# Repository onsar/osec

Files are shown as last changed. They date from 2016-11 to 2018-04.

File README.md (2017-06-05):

# osec
###Proyecto de para el desarrollo de un demostrador de software libre para el control de la energía

En la primera fase monitorizamos una instalación solar fotovoltaica mixta que esta compuesta por paneles fotovoltaicos y térmicos. Los tipos de sensores que incluye son:

* Intensidad en continua
* Temperatura del agua
* Caudal
* Presión del circuito hidráulico

En una segunda fases optimizaremos el circuito

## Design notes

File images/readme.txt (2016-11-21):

En este directorio actualizaremos las imágenes que vayamos a usar en la documentación del proyecto

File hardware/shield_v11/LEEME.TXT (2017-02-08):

Esta versión incorpora la alimentación directa de la entrada al RD-xx15

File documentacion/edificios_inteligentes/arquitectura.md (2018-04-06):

# Descripción de la arquitectura

El sistema de control inteligente MeshControl está formado por una serie de componentes que abarca desde los sensores y actuadores anteriormente nombrados, al software y hardware de la unidad interior. La tecnología de la que se compone MeshControl es abierta, permitiendo y facilitando su acceso a fabricantes e instaladores que quieran implementarla en sus sistemas. Por ello, la licencia bajo la que se distribuirá el producto es GPL (General Public License), lo que garantiza la colaboración entre los usuarios y redunda en una mejora continua del sistema. 

## Hardware

Siguiendo los principios de la tecnología abierta, el hardware del proyecto se ha desarrollado bajo licencias libres de manera que esta solución se pueda replicar en otras aplicaciones o modificar para adaptarlo a las necesidades específicas de una instalación. Por ello, el hadware específico desarrollado para este proyecto está basado en los microcontroladores de Atmel, que son el corazón de Arduino. Para los módulos que necesiten prestaciones más altas se usa la Raspberry Pi y el hardware Olimex. 
El dispositivo físico que se dispondrá en cada instalación solar está basado en una PCB (Printed Circuit Board), a la cual se ha integrado uno de estos microcontroladores que se encarga del control de la información. Junto al microcontrolaador se incluye también el integrado ESP 8266, fabricado por Espressif, un módulo WIFI de fácil manejo y muy económico, capaz de conectar cualquier dispositivo a la red y cuyo uso se está extendiendo notablemente en las soluciones de IoT. Este chip es por tanto el encargado de transmitir la información recibida a la nube.

## Software

La información obtenida a través de los distintos canales de entrada se almacena en una base de datos localizada en la nube, concretamente en un servidor habilitado para cada instalación. La transmisión de información desde la fuente local al servidor se realiza mediante protocolos Restful y Mqtt, este último muy usado en soluciones IoT debido al poco consumo de recursos que conlleva. A diferencia de otros sistemas de control, diseñados para sistemas solares, el software específico de MeshControl se aloja directamente en el servidor, de manera que la información recibida es procesada directamente ahí. Este hecho constituye una ventaja fundamental, ya que facilita su acceso desde cualquier punto con conexión a internet a la vez que se favorece la integración con otros servicios que alojados en la nube. El servidor desarrollado está basado en PHP y JavaScript que permiten tanto al técnico responsable como al usuario final acceder directamente a sus datos registrados, visualizar estadísticas y consumos o modificar parámetros de funcionamiento del sistema. Para ello, se ha tomado como referencia el software Emoncms, el cual se ha modificado para cubrir las exigencias de los sistemas solares híbridos.
La comunicación entre el servidor y actuadores se ejecuta también mediante protocolos Restful y Mqtt. Se ha hecho especial hincapié en el uso de protocolos web y redes WIFI con el fin de aumentar la flexibilidad del sistema de control, ya que de esta manera se reducen las infraestructuras de cableado y sus problemas típicos asociados. Además, actualmente los dispositivos WIFI son una tecnología robusta, extendida y de precio muy competitivo, que junto con el envío de información mediante protocolo Mqtt redunda en un consumo de energía muy reducido.

[MODIFICAR IMAGEN]

La implementación del servidor en la nube respalda directamente la premisa del Internet de las Cosas, ya que la información se recibe, se muestra y se gestiona desde internet. Este tratamiento presenta varias ventajas clave sobre otros sistemas de control efectuados en tecnologías solares. En primer lugar transporta el sistema de control fuera de la instalación física, lo que evita el traslado del técnico especialista hasta el entorno real cada vez que haya que ejecutar una modificación o reparar una avería. Por contra, ese control se lleva a un entorno en la nube que es fácilmente accesible por todos los agentes (técnico, instalador, usuario final) y al que se puede llegar con una simple conexión a internet. Al crear un servidor para cada instalación se reduce el riesgo de provocar problemas que afecten a un gran número de usuarios, mientras que se favorece por otra parte, la adecuación del software a las necesidades de cada instalación en particular. Por último, generar un entorno en la nube donde el usuario final pueda revisar periódicamente la producción y consumos de su vivienda, ayuda a visualizar y a tomar conciencia de su propia gestión energética y de los beneficios obtenidos mediante el control inteligente de la instalación solar, lo que puede contribuir a aumentar la confianza en dicha tecnología.

## La robustez del sistema
Los microcontroladores, que recopilan la información de la red de sensores y ejecutan las acciones, leen del sistema en la nube cual debe ser su comportamiento (actualizan su software) lo que protege a MEshControl contra fallos en las comunicaciones o en el propio servidor. Esta característica proporciona un sistema robusto que funcionará ante cualquier contingencia y que a la vez se beneficia de todas las ventajas de estar en la nube.

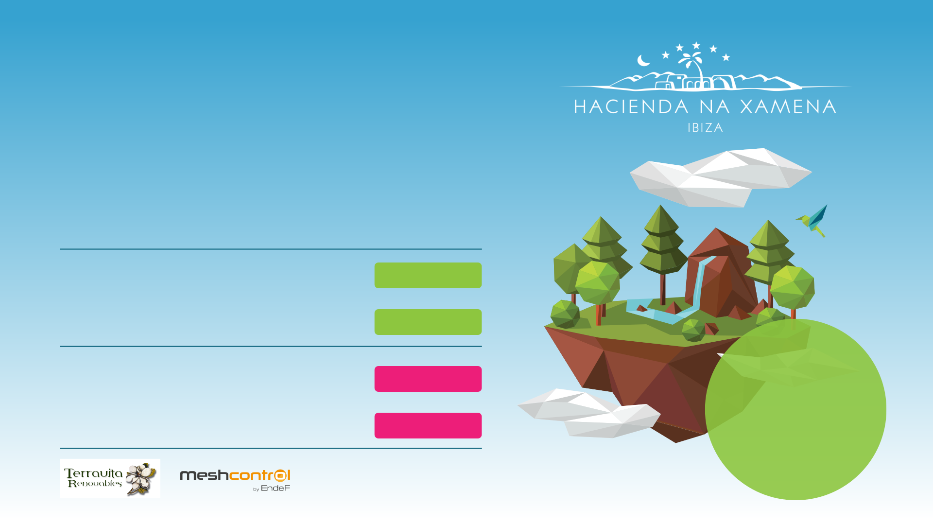
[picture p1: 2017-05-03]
interfaz.a-desarrollo/img/back.png

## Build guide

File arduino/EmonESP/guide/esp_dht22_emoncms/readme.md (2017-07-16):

# ESP DHT22 to Emoncms Example

An example made using the [Adafruit Huzzah](https://www.adafruit.com/product/2471) board with ESP-12 module and the DHT22 temperature humidity sensor.

This code example, when loaded onto the ESP will continuously upload temperature and humidity data onto [emoncms.org](https://emoncms.org)

[CP2102 USB to UART adapter](https://shop.openenergymonitor.com/programmers) was used as power supply and to program the ESP. 
PlatformIO or Arduino IDE can be used to compile and upload code. See [PlatformIO compile and upload guide](https://guide.openenergymonitor.org/technical/compiling)

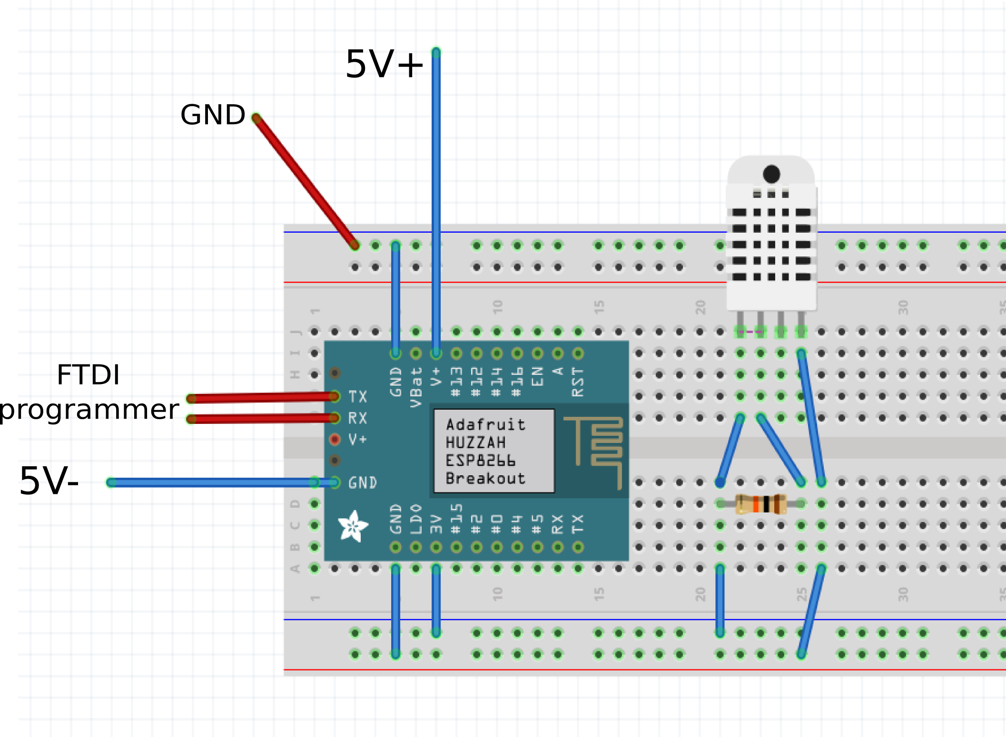
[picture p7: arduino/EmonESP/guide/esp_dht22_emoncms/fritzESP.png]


Thanks to @myrddinmuse for puting together this example.

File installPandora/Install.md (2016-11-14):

Insatalacion de pandora en un sistema debian, incluyendo consola, servidor y agente.

Para empezar descargamos los paquetes desde el siguiente enlace: Enlace (https://pandorafms.org/en/features/free-download-monitoring-software/)

Luego instalamos los paquetes con los siguientes comandos <br>
  <code>### XXX es la version del paquete.  </code><br>
  <code># dpkg -i pandorafms.console_XXX.deb  </code><br>
  <code># apt-get -f install  </code><br>
  <code># dpkg -i pandorafms.server_XXX.deb </code><br>
  <code># apt-get -f install </code><br>
  <code># dpkg -i pandorafms.agent_XXX.deb  </code><br>
  <code># apt-get -f install  </code><br>

Ahora hay que instalar el servidor de la base de datos MySQL <br><br>
  <code># apt-get install mysql-server </code><br><br>
En esta instalacion pedira un usuario y contraseña para el usuario administrador de la base de datos.

Despues se modifica el fichero “etc/apache2/sites-enabled/000-default.conf” para hacer de la consola la pagina de inicio
cambiando la linea “DocumentRoot /var/www/pandora_console”. Y se reinicia el servicio de apache con el siguiente comando:
  <br><br>
  <code># /etc/init.d/apache2 restart </code><br><br>

Luego de reiniciar el servicio abrimos un navegador y vamos a la ip del servidor (o a localhost si estamos en el servidor)
  <br><br>
  <code>http://192.168.xxx.xxx/install.php</code><br>
  o<br>
  <code>http://localhost/install.php</code><br><br>
  
En esta instalacion debemos darle usuario y clave de la base de datos MySQL a la consola de pandora. <br>
Es importante escribir la contraseña que nos da pandora durante la instalacion, en:
  <br><br>
  <code># /etc/pandora/pandora_server.conf</code><br>
  <code>systemctl restart pandora_server.service</code>

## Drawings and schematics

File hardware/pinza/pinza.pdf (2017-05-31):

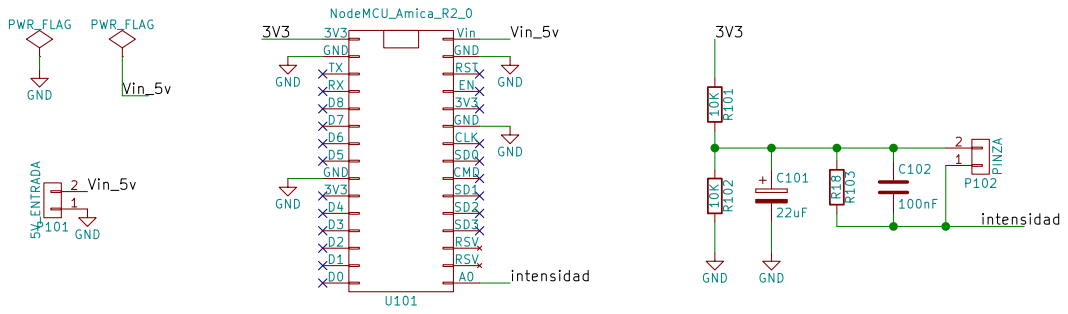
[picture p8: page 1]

File: pinza.sch Sheet: /
Id: 1/1 Title:

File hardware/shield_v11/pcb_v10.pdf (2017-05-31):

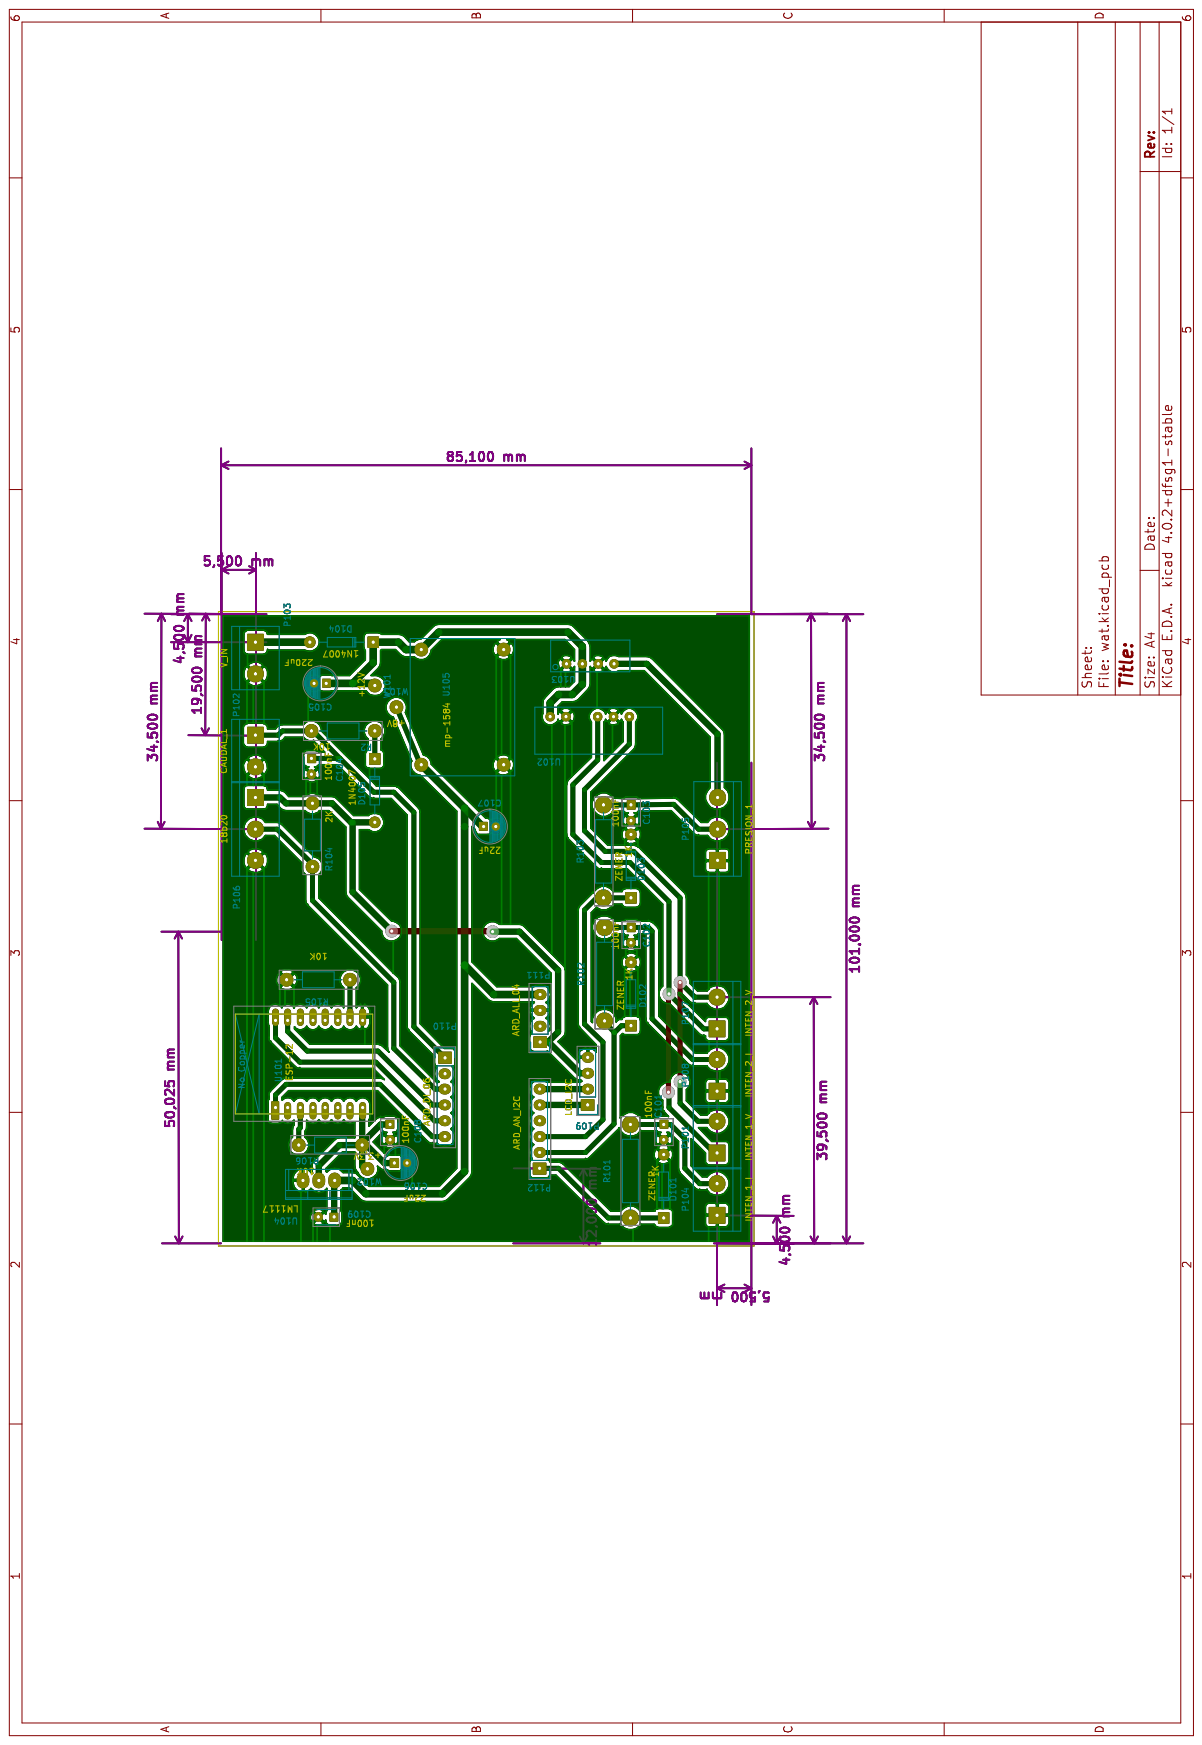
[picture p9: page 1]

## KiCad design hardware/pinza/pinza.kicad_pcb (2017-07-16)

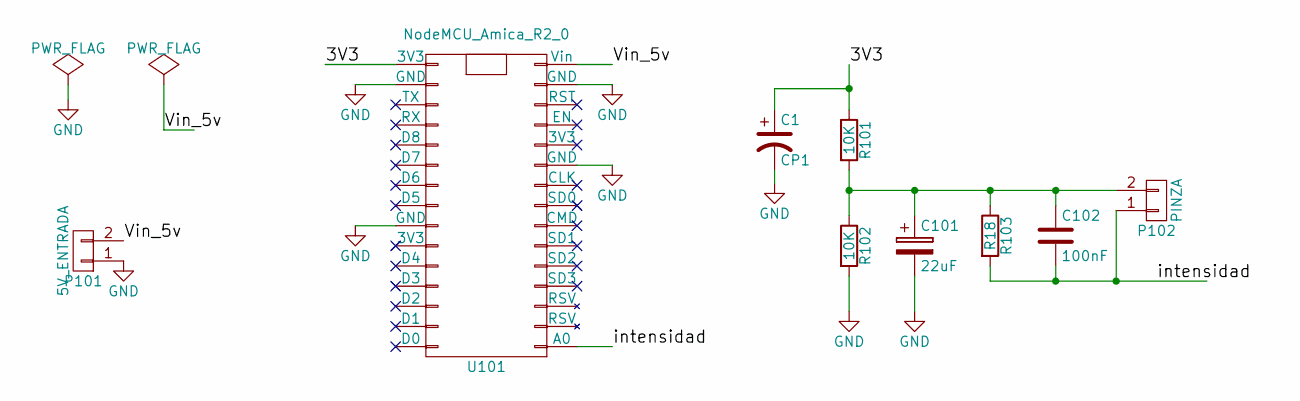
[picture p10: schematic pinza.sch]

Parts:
C1: CP1; C_Radial_D5_L11_P2
C101: 22uF; C_Radial_D5_L11_P2
C102: 100nF; C_Disc_D3_P2.5
P101: 5V_ENTRADA; bornier2
P102: PINZA; bornier2
R101, R102: 10K; Resistor_Horizontal_RM10mm
R103: R18; Resistor_Horizontal_RM10mm
U101: NodeMCU_Amica_R2_0; NodeMCU_Amica_R2

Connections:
/3V3: C1.1, R101.1, U101.16 (3V3)
/Vin_5v: P101.2, U101.15 (Vin)
/intensidad: C102.2, P102.1, R103.2, U101.1 (A0)
GND: C1.2, C101.2, P101.1, R102.2, U101.10 (GND), U101.14 (GND), U101.17 (GND), U101.24 (GND)
unnamed: C101.1, C102.1, P102.2, R101.2, R102.1, R103.1

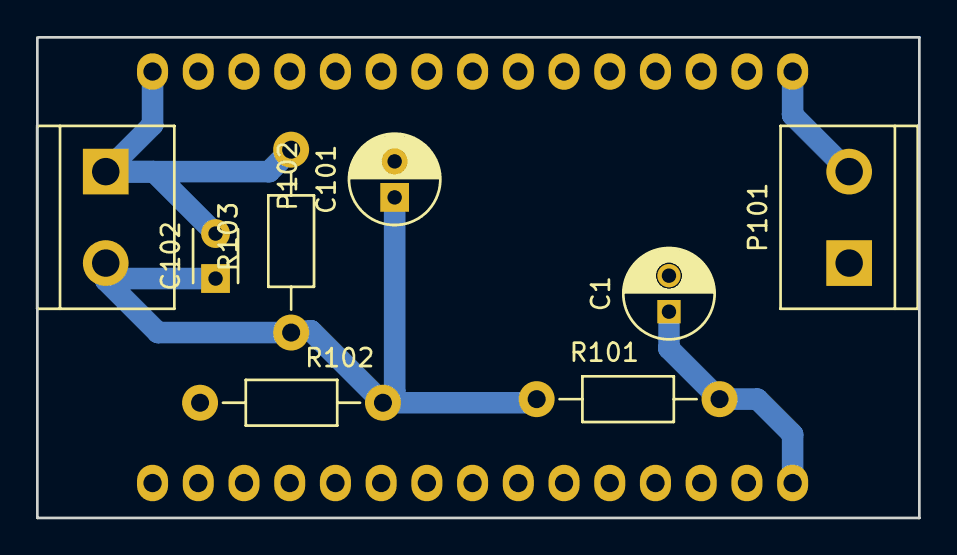
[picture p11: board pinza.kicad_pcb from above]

Board: 2 copper layers, 49.0 x 26.7 mm, 9 parts (1 on the bottom side), 5 nets.

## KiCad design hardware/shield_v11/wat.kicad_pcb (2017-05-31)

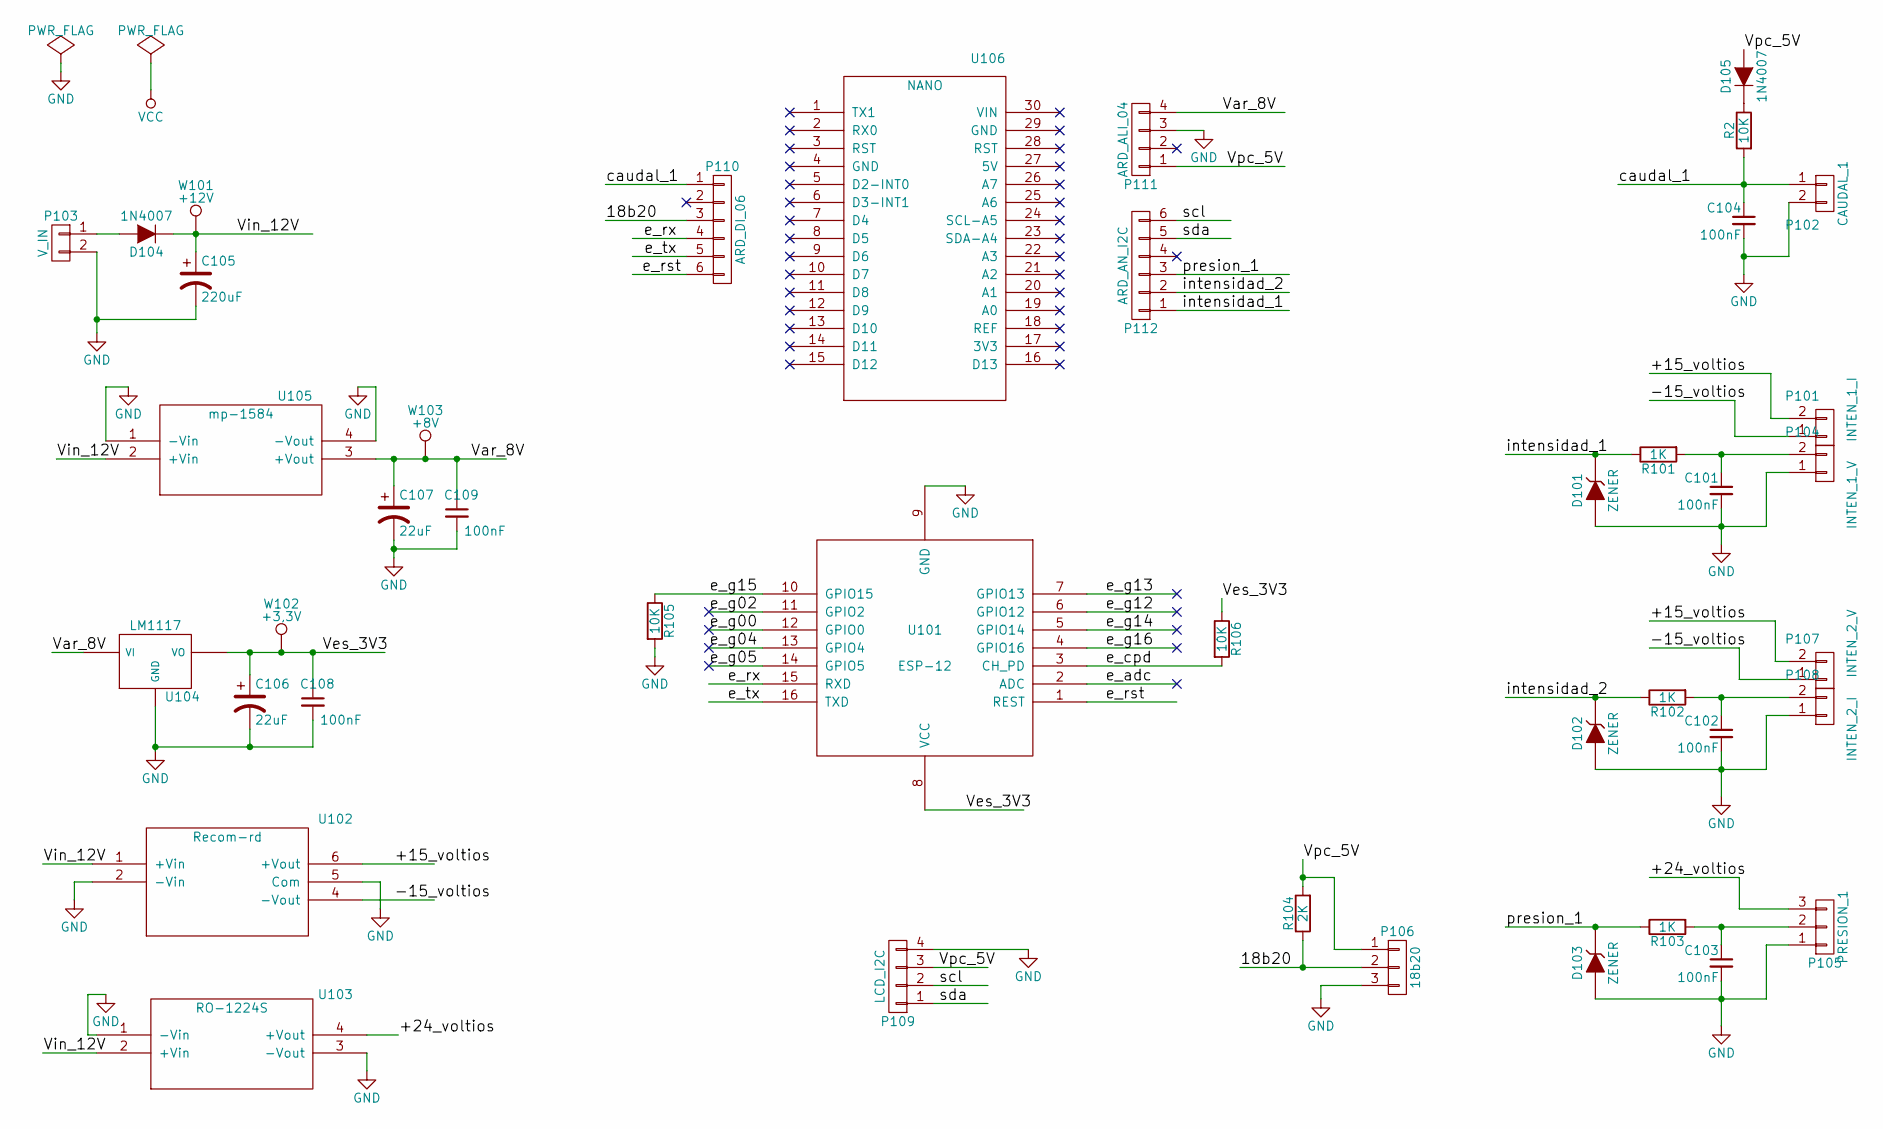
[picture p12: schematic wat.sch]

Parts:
C101, C102, C103, C104, C108, C109: 100nF; C_Disc_D3_P2.5
C105: 220uF; C_Radial_D5_L11_P2
C106, C107: 22uF; C_Radial_D5_L11_P2
D101, D102, D103: ZENER; Diode_DO-35_SOD27_Horizontal_RM10
D104, D105: 1N4007; Diode_DO-35_SOD27_Horizontal_RM10
P101: INTEN_1_V; bornier2
P102: CAUDAL_1; bornier2
P103: V_IN; bornier2
P104: INTEN_1_I; bornier2
P105: PRESION_1; bornier3
P106: 18b20; bornier3
P107: INTEN_2_V; bornier2
P108: INTEN_2_I; bornier2
P109: LCD_I2C; Pin_Header_Straight_1x04
P110: ARD_DI_06; Pin_Header_Straight_1x06
P111: ARD_ALI_04; Pin_Header_Straight_1x04
P112: ARD_AN_I2C; Pin_Header_Straight_1x06
R2, R105, R106: 10K; Resistor_Horizontal_RM10mm
R101, R102, R103: 1K; Resistor_RM15mm_pad
R104: 2K; Resistor_Horizontal_RM10mm
U101: ESP-12; ESP-07v2_pad
U102: Recom-rd
U103: RO-1224S; RO-xxxxS
U104: LM1117; TO-220-LM117
U105: mp-1584; MP-1584-SD
U106: NANO; arduino_nano
W101: +12V; SolderWirePad_single_0-8mmDrill
W102: +3,3V; SolderWirePad_single_0-8mmDrill
W103: +8V; SolderWirePad_single_0-8mmDrill

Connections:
/18b20: P106.2, P110.3, R104.1
/+15_voltios: P101.2, P107.2, U102.6 (+Vout)
/+24_voltios: P105.3, U103.4 (+Vout)
/-15_voltios: P101.1, P107.1, U102.4 (-Vout)
/Var_8V: C107.1, C109.1, P111.4, U104.VI, U105.3 (+Vout), W103.1
/Ves_3V3: C106.1, C108.1, R106.1, U101.8 (VCC), U104.VO, W102.1
/Vin_12V: C105.1, D104.1 (K), U102.1 (+Vin), U103.2 (+Vin), U105.2 (+Vin), W101.1
/Vpc_5V: D105.2 (A), P106.1, P109.3, P111.1, R104.2
/caudal_1: C104.1, P102.1, P110.1, R2.2
/e_adc: U101.2 (ADC)
/e_cpd: R106.2, U101.3 (CH_PD)
/e_g00: U101.12 (GPIO0)
/e_g02: U101.11 (GPIO2)
/e_g04: U101.13 (GPIO4)
/e_g05: U101.14 (GPIO5)
/e_g12: U101.6 (GPIO12)
/e_g13: U101.7 (GPIO13)
/e_g14: U101.5 (GPIO14)
/e_g15: R105.1, U101.10 (GPIO15)
/e_g16: U101.4 (GPIO16)
/e_rst: P110.6, U101.1 (REST)
/e_rx: P110.4, U101.15 (RXD)
/e_tx: P110.5, U101.16 (TXD)
/intensidad_1: D101.1 (K), P112.1, R101.1
/intensidad_2: D102.1 (K), P112.2, R102.1
/presion_1: D103.1 (K), P112.3, R103.1
/scl: P109.2, P112.6
/sda: P109.1, P112.5
GND: C101.2, C102.2, C103.2, C104.2, C105.2, C106.2, C107.2, C108.2, C109.2, D101.2 (A), D102.2 (A), D103.2 (A), P102.2, P103.2, P104.1, P105.1, P106.3, P108.1, P109.4, P111.3, R105.2, U101.9 (GND), U102.2 (-Vin), U102.5 (Com), U103.1 (-Vin), U103.3 (-Vout), U104.GND, U105.1 (-Vin), U105.4 (-Vout)
unnamed: C101.1, P104.2, R101.2
unnamed: C102.1, P108.2, R102.2
unnamed: C103.1, P105.2, R103.2
unnamed: D104.2 (A), P103.1
unnamed: D105.1 (K), R2.1

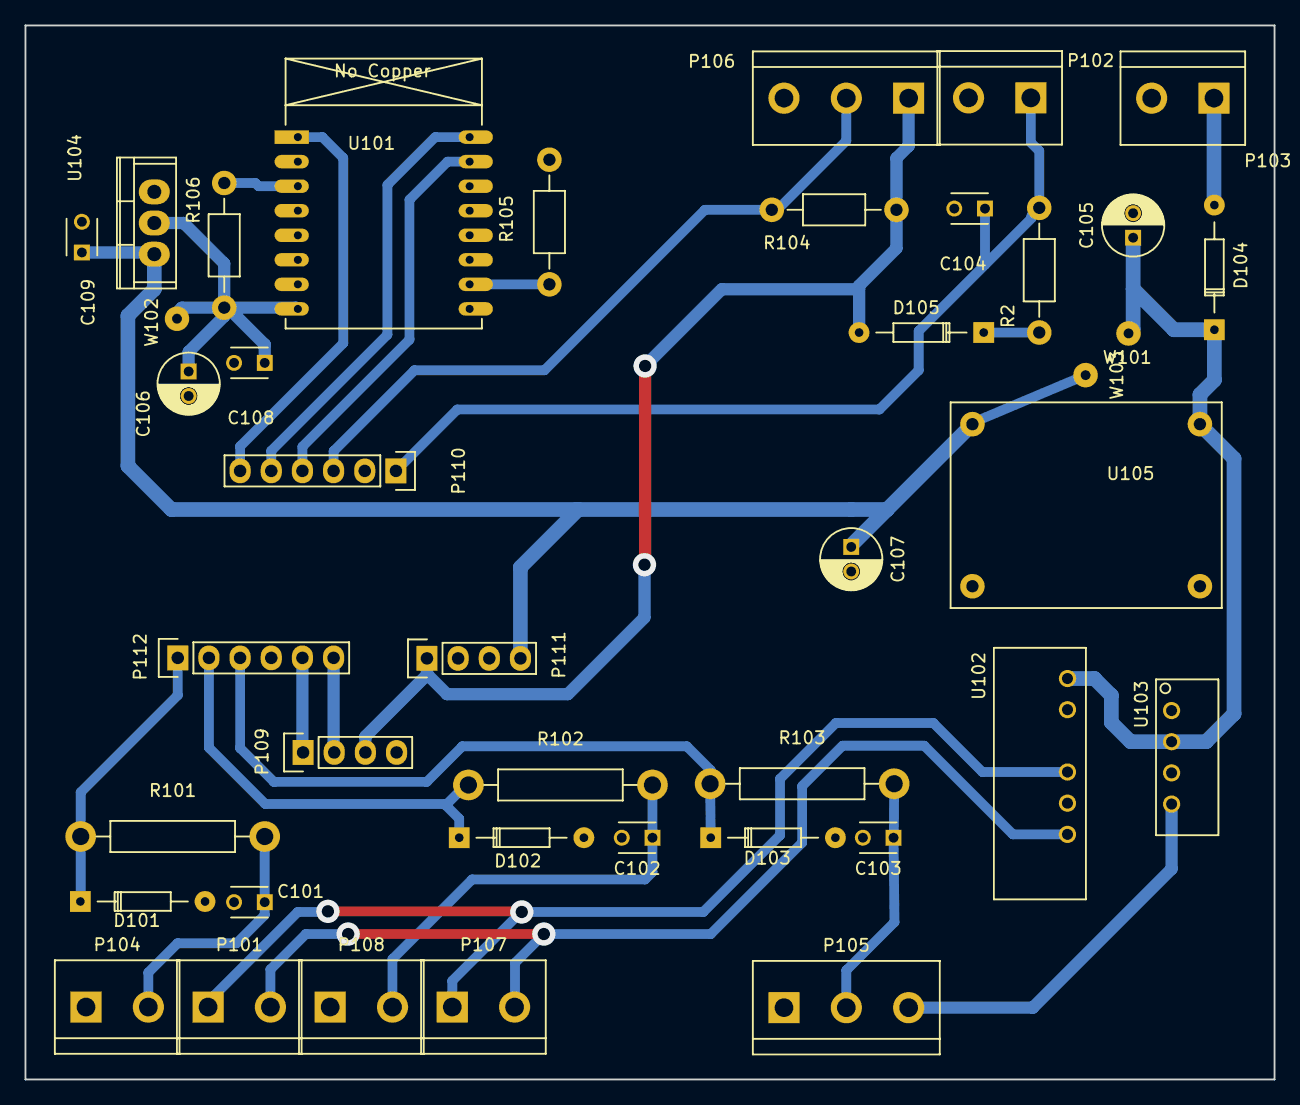
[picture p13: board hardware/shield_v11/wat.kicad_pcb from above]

Board: 2 copper layers, 101.8 x 85.9 mm, 41 parts (0 on the bottom side), 25 nets.

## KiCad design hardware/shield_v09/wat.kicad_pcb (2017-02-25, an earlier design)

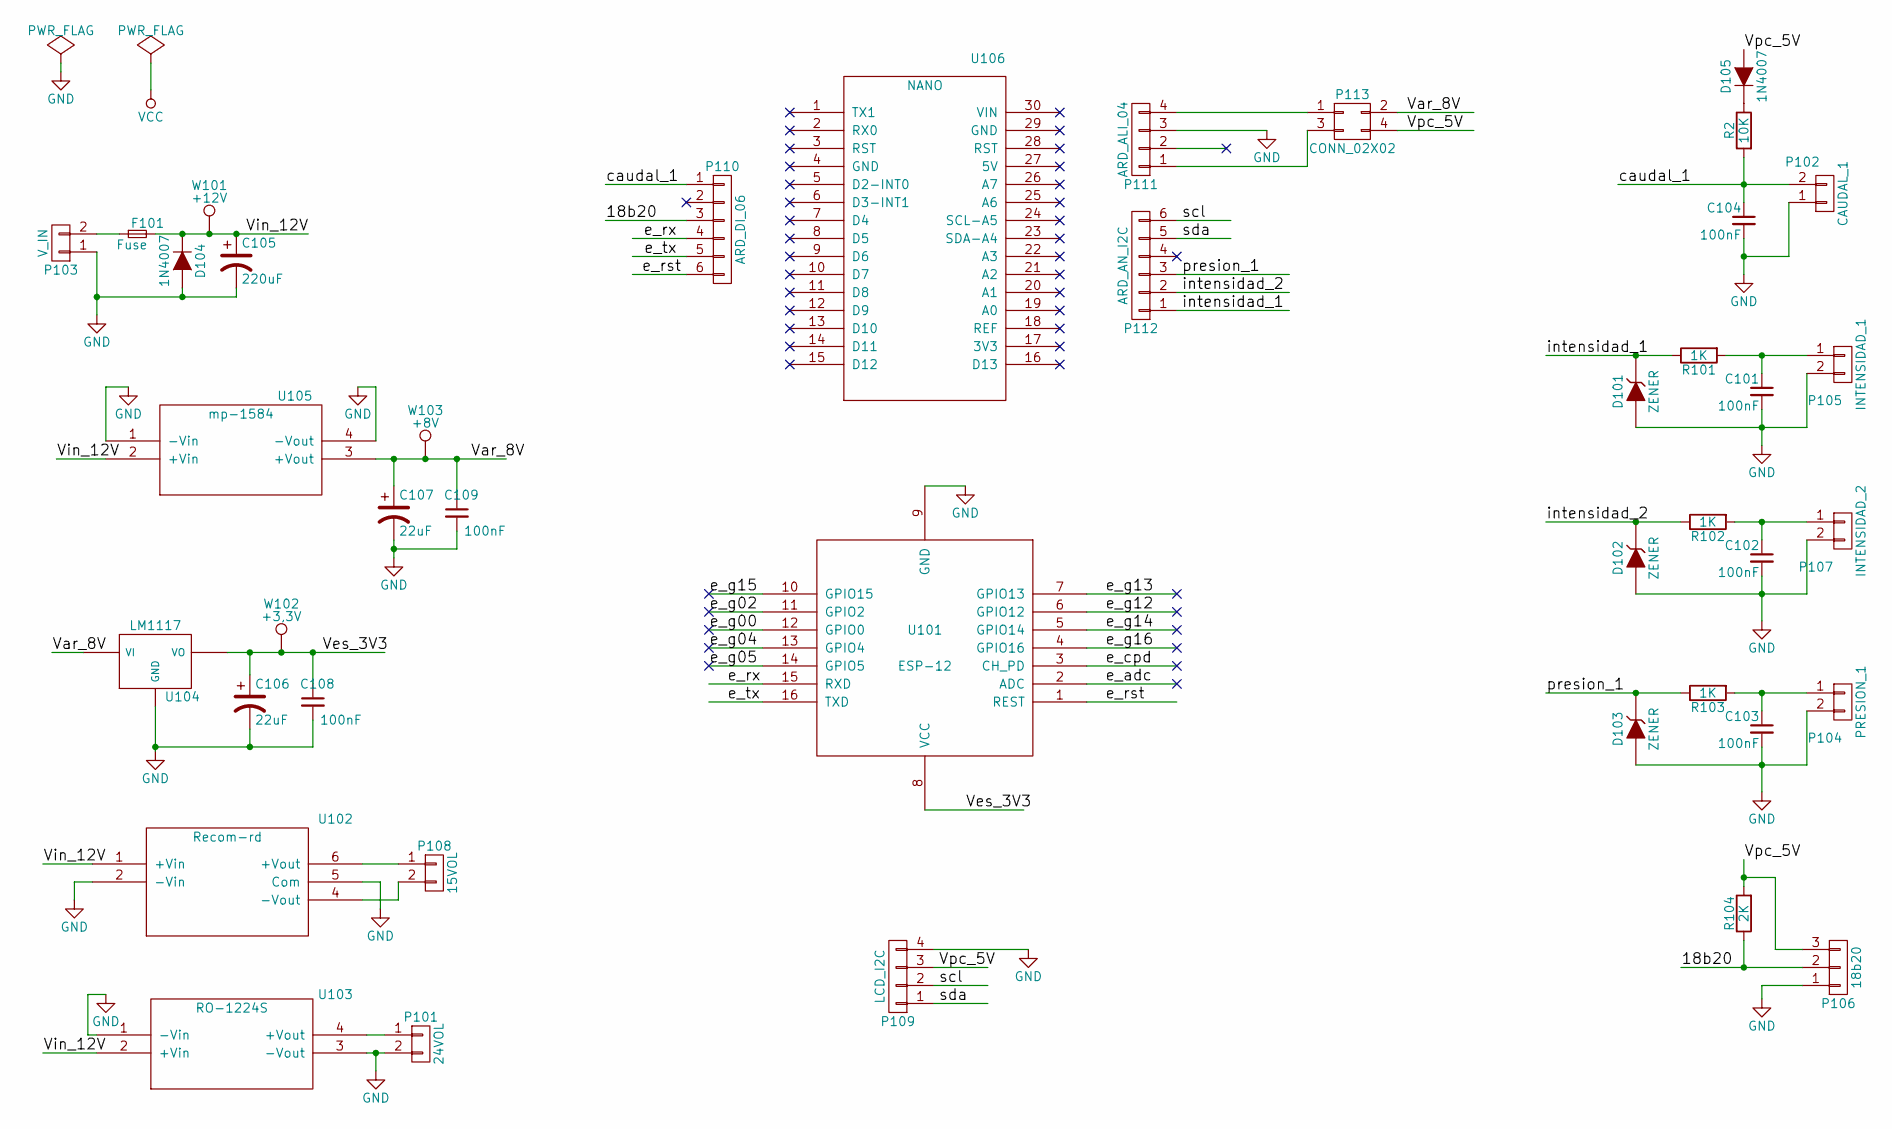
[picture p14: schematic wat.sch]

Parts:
C101, C102, C103, C104, C108, C109: 100nF; C_Disc_D3_P2.5
C105: 220uF; C_Radial_D5_L11_P2
C106, C107: 22uF; C_Radial_D5_L11_P2
D101, D102, D103: ZENER; Diode_DO-35_SOD27_Horizontal_RM10
D104, D105: 1N4007; Diode_DO-35_SOD27_Horizontal_RM10
F101: Fuse; Fuseholder_Fuse_TR5_Littlefuse-No560_No460
P101: 24VOL; bornier2
P102: CAUDAL_1; bornier2
P103: V_IN; bornier2
P104: PRESION_1; bornier2
P105: INTENSIDAD_1; bornier2
P106: 18b20; bornier3
P107: INTENSIDAD_2; bornier2
P108: 15VOL; bornier2
P109: LCD_I2C; Pin_Header_Straight_1x04
P110: ARD_DI_06; Pin_Header_Straight_1x06
P111: ARD_ALI_04; Pin_Header_Straight_1x04
P112: ARD_AN_I2C; Pin_Header_Straight_1x06
P113: CONN_02X02; Pin_Header_Straight_2x02
R2: 10K; Resistor_Horizontal_RM10mm
R101, R102, R103: 1K; Resistor_Horizontal_RM15mm
R104: 2K; Resistor_Horizontal_RM10mm
U101: ESP-12; ESP-07v2
U102: Recom-rd
U103: RO-1224S; RO-xxxxS
U104: LM1117; TO-220
U105: mp-1584; MP-1584-SD
U106: NANO; arduino_nano
W101: +12V; SolderWirePad_single_0-8mmDrill
W102: +3,3V; SolderWirePad_single_0-8mmDrill
W103: +8V; SolderWirePad_single_0-8mmDrill

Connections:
/18b20: P106.2, P110.3, R104.1
/Var_8V: C107.1, C109.1, P113.2, U104.VI, U105.3 (+Vout), W103.1
/Ves_3V3: C106.1, C108.1, U101.8 (VCC), U104.VO, W102.1
/Vin_12V: C105.1, D104.1 (K), F101.2, U102.1 (+Vin), U103.2 (+Vin), U105.2 (+Vin), W101.1
/Vpc_5V: D105.2 (A), P106.3, P109.3, P113.4, R104.2
/caudal_1: C104.1, P102.2, P110.1, R2.2
/e_adc: U101.2 (ADC)
/e_cpd: U101.3 (CH_PD)
/e_g00: U101.12 (GPIO0)
/e_g02: U101.11 (GPIO2)
/e_g04: U101.13 (GPIO4)
/e_g05: U101.14 (GPIO5)
/e_g12: U101.6 (GPIO12)
/e_g13: U101.7 (GPIO13)
/e_g14: U101.5 (GPIO14)
/e_g15: U101.10 (GPIO15)
/e_g16: U101.4 (GPIO16)
/e_rst: P110.6, U101.1 (REST)
/e_rx: P110.4, U101.15 (RXD)
/e_tx: P110.5, U101.16 (TXD)
/intensidad_1: D101.1 (K), P112.1, R101.1
/intensidad_2: D102.1 (K), P112.2, R102.1
/presion_1: D103.1 (K), P112.3, R103.1
/scl: P109.2, P112.6
/sda: P109.1, P112.5
GND: C101.2, C102.2, C103.2, C104.2, C105.2, C106.2, C107.2, C108.2, C109.2, D101.2 (A), D102.2 (A), D103.2 (A), D104.2 (A), P101.2, P102.1, P103.1, P104.2, P105.2, P106.1, P107.2, P109.4, P111.3, U101.9 (GND), U102.2 (-Vin), U102.5 (Com), U103.1 (-Vin), U103.3 (-Vout), U104.GND, U105.1 (-Vin), U105.4 (-Vout)
unnamed: C101.1, P105.1, R101.2
unnamed: C102.1, P107.1, R102.2
unnamed: C103.1, P104.1, R103.2
unnamed: D105.1 (K), R2.1
unnamed: F101.1, P103.2
unnamed: P101.1, U103.4 (+Vout)
unnamed: P108.1, U102.6 (+Vout)
unnamed: P108.2, U102.4 (-Vout)
unnamed: P111.1, P113.3
unnamed: P111.4, P113.1

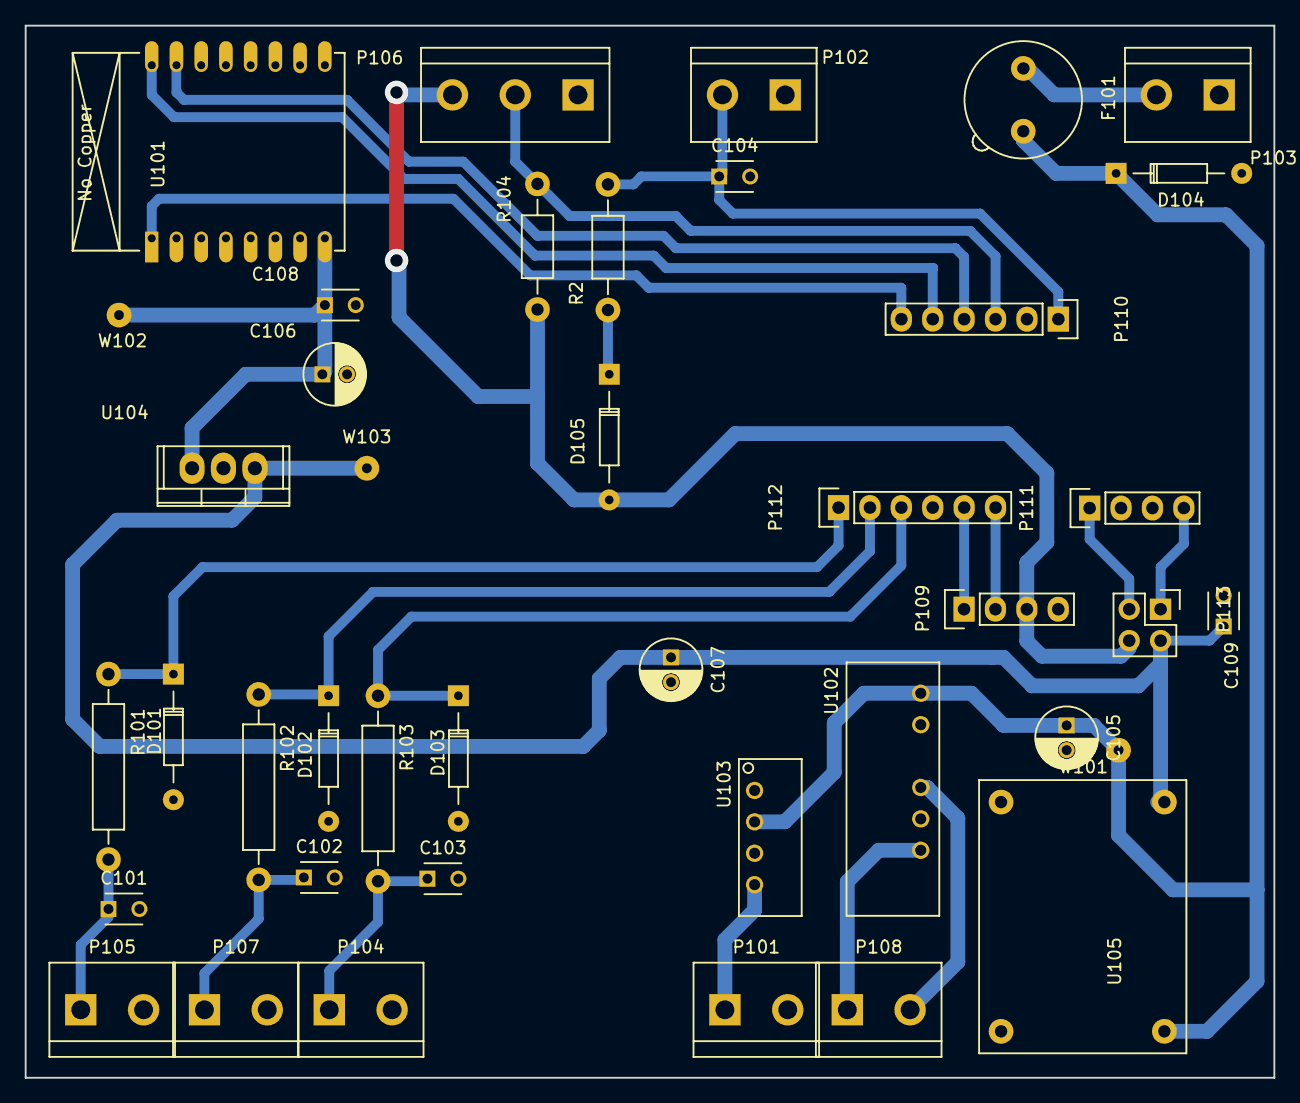
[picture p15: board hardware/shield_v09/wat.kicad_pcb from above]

Board: 2 copper layers, 101.0 x 85.1 mm, 41 parts (0 on the bottom side), 25 nets.

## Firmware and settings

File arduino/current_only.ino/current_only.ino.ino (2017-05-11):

// EmonLibrary examples openenergymonitor.org, Licence GNU GPL V3

#include "EmonLib.h"                   // Include Emon Library
EnergyMonitor emon1;                   // Create an instance

void setup()
{  
  Serial.begin(115200);
  
  emon1.current(A0, 111.1);             // Current: input pin, calibration.
}

void loop()
{
  double Irms = emon1.calcIrms(1480);  // Calculate Irms only

  Serial.print("**************** ");
  Serial.print(Irms*230.0);         // Apparent power
  Serial.print(" ");
  Serial.println(Irms);          // Irms
}

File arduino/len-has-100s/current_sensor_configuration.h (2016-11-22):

#ifndef current_sensor_configuration_h
#define current_sensor_configuration_h


#define CURRENT_DEVICES_NUMBER 3

#define  CURRENT_INPUT_1  0
#define  CURRENT_SENSOR_NAME_1 " INTENSIDAD DE ENTRADA PLACAS" 

#define  CURRENT_INPUT_2  1
#define  CURRENT_SENSOR_NAME_2 " INTENSIDAD DE SALIDA" 

#define  CURRENT_INPUT_3  5
#define  CURRENT_SENSOR_NAME_3 " INTENSIDAD TOTAL" 

#define  CURRENT_INPUT_4  99
#define  CURRENT_SENSOR_NAME_4 " NOMBRE DESCONOCIDO" 

#define  CURRENT_INPUT_5  99
#define  CURRENT_SENSOR_NAME_5 " NOMBRE DESCONOCIDO" 

#define  CURRENT_INPUT_6  99
#define  CURRENT_SENSOR_NAME_6 " NOMBRE DESCONOCIDO" 

#endif

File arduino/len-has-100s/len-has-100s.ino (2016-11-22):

// definies
#include "current_sensor_configuration.h"

// variable declaration
int pinCurrentSensor[CURRENT_DEVICES_NUMBER];

// Function Prototypes
void currentSensorMessage();
void printDataCurrentSensor(int); 
void printCurrent(int);
 
 

void setup() 
    {
        // initialize serial communication at 9600 bits per second:
        Serial.begin(9600);
        
        // current pins sensor matrix
        if (CURRENT_DEVICES_NUMBER > 0) pinCurrentSensor[0]=CURRENT_INPUT_1;
        if (CURRENT_DEVICES_NUMBER > 1) pinCurrentSensor[1]=CURRENT_INPUT_2;
        if (CURRENT_DEVICES_NUMBER > 2) pinCurrentSensor[2]=CURRENT_INPUT_3;    
        if (CURRENT_DEVICES_NUMBER > 3) pinCurrentSensor[3]=CURRENT_INPUT_4;    
        if (CURRENT_DEVICES_NUMBER > 4) pinCurrentSensor[4]=CURRENT_INPUT_5;    
        if (CURRENT_DEVICES_NUMBER > 5) pinCurrentSensor[5]=CURRENT_INPUT_6; 
        

        
        //maintenance message

        Serial.print("{\"maint_data_curr_sensor\":{"); 

        // Search the wire for address
        if(CURRENT_DEVICES_NUMBER)
            {
                currentSensorMessage();
            }

        else
            {
                Serial.print("NO HAY DISPOSITIVOS CONFIGURADOS. ");
                Serial.print("Revisa el fichero de configuración:current_sensor_configuration.h");
            }

        // Close mintenence, message
        Serial.println("}}"); 
        
    }

void loop() 
    {
        currentSensorMessage();
    }



void currentSensorMessage()
    {
        // esta repetido en los otros mensajes
        uint32_t time = millis();
        
        // cabecera del mensaje
        Serial.print("{\"data_sensor\":{\"code\":\"50001\",\"number\":\"001\",\"name\":\"San Pablo\",\"time_0x\":\""); 
        Serial.print(time); 
        Serial.print("\",");
        
        // current message for each sensor
        Serial.print("\"current_sensors\":{");
        
        for(int i=0;i<CURRENT_DEVICES_NUMBER; i++)
            {
                printDataCurrentSensor(i); 
                if (i < (CURRENT_DEVICES_NUMBER-1))Serial.print(",");
                
            }
            
        // close data_sensor,message    
        Serial.println("}}}");
    
    }
void printDataCurrentSensor(int n) 
    {
        // current id
        Serial.print("\"sensor_");
        Serial.print(n);
        Serial.print("\":{");
        Serial.print("\"id\":\"");
        Serial.print(pinCurrentSensor[n]);
        Serial.print("\","); 
    
        // current sensor name
        Serial.print("\"name\":\"");
        if      (pinCurrentSensor[n]== CURRENT_INPUT_1)   {Serial.print(CURRENT_SENSOR_NAME_1); }
        else if (pinCurrentSensor[n]== CURRENT_INPUT_2)   {Serial.print(CURRENT_SENSOR_NAME_2); }
        else if (pinCurrentSensor[n]== CURRENT_INPUT_3)   {Serial.print(CURRENT_SENSOR_NAME_3); }
        else if (pinCurrentSensor[n]== CURRENT_INPUT_4)   {Serial.print(CURRENT_SENSOR_NAME_4); }            
        else if (pinCurrentSensor[n]== CURRENT_INPUT_5)   {Serial.print(CURRENT_SENSOR_NAME_5); }            
        else if (pinCurrentSensor[n]== CURRENT_INPUT_6)   {Serial.print(CURRENT_SENSOR_NAME_6); }            
        else {Serial.print( "Nombre no declarado"); }            
        Serial.print("\","); 
            
        // current data
        Serial.print("\"curr\":\"");
        printCurrent(pinCurrentSensor[n]);
        Serial.print("\"");
        
        Serial.print("}"); // sensor close
    }


void printCurrent(int pin)
    {
        uint32_t sensorValue = analogRead(pin);
        // Convert the analog reading (which goes from 0 - 1023) to a voltage (0 - 5V):
        uint32_t voltage = sensorValue * (5000 / 1023);
        // print out the value you read:
        Serial.print(voltage); 
    }

  

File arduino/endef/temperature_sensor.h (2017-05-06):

#ifndef temperature_sensor_h
#define temperature_sensor_h


// *******************************************************
// ******** CONFIGURACION SENSORES DE TEMPERATURA ********
// *******************************************************

// #define ONE_WIRE_BUS 6 // arduino uno
#define ONE_WIRE_BUS 4 // arduino nano

// Lower resolution
#define TEMPERATURE_PRECISION 9

//#define POSITION_1  {0x28,0xFF,0xFD,0x36,0x84,0x16,0x04,0x98}
#define POSITION_1  {0x28,0xA3,0x77,0x02,0x08,0x00,0x00,0x05}
#define NAME_SENSOR_1 "Temp_Out" 
#define POSITION_2  {0x28,0x7B,0x6B,0x02,0x08,0x00,0x00,0x3D}
#define NAME_SENSOR_2 "Temp_In" 
#define POSITION_3  {0x28,0x53,0x8E,0x01,0x08,0x00,0x00,0xAA}
#define NAME_SENSOR_3 "Temp_Amb"
#define POSITION_4  {0x28,0xFF,0x86,0x40,0x70,0x16,0x05,0x69}
#define NAME_SENSOR_4 "Tra Planta 3" 
#define POSITION_5  {0xEE,0xEE,0xEE,0xEE,0xEE,0xEE,0xEE,0xEE}
#define NAME_SENSOR_5 " SENSOR POSITION" 
#define POSITION_6  {0xEE,0xEE,0xEE,0xEE,0xEE,0xEE,0xEE,0xEE}
#define NAME_SENSOR_6 " SENSOR POSITIONL" 
#define POSITION_7  {0xEE,0xEE,0xEE,0xEE,0xEE,0xEE,0xEE,0xEE}
#define NAME_SENSOR_7 " SENSOR POSITION" 
#define POSITION_8  {0xEE,0xEE,0xEE,0xEE,0xEE,0xEE,0xEE,0xEE}
#define NAME_SENSOR_8 " SENSOR POSITION" 
#define POSITION_9  {0xEE,0xEE,0xEE,0xEE,0xEE,0xEE,0xEE,0xEE}
#define NAME_SENSOR_9 " SENSOR POSITION"
#define POSITION_10  {0xEE,0xEE,0xEE,0xEE,0xEE,0xEE,0xEE,0xEE}
#define NAME_SENSOR_10 " SENSOR POSITION"
#define POSITION_11  {0xEE,0xEE,0xEE,0xEE,0xEE,0xEE,0xEE,0xEE}
#define NAME_SENSOR_11 " SENSOR POSITION" 
#define POSITION_12  {0xEE,0xEE,0xEE,0xEE,0xEE,0xEE,0xEE,0xEE}
#define NAME_SENSOR_12 " SENSOR POSITION" 


// *******************************************************

#include <OneWire.h>
#include <DallasTemperature.h>

void buildTemperatureMessage(uint8_t);
String printName(DeviceAddress deviceAddress);
bool compareAddress(DeviceAddress deviceAddress_c_1, DeviceAddress deviceAddress_c_2);
void printResoltion(DeviceAddress deviceAddressPr);
String printAddress(DeviceAddress deviceAddressPa);
void temperatureSensorsBegin();


DeviceAddress tempDeviceAddress;
OneWire oneWire(ONE_WIRE_BUS);
DallasTemperature sensors_m(&oneWire);


 //DeviceAddress
uint8_t deviceAddress_1[]=POSITION_1;
uint8_t deviceAddress_2[]=POSITION_2;
uint8_t deviceAddress_3[]=POSITION_3;
uint8_t deviceAddress_4[]=POSITION_4;
uint8_t deviceAddress_5[]=POSITION_5;
uint8_t deviceAddress_6[]=POSITION_6;
uint8_t deviceAddress_7[]=POSITION_7;
uint8_t deviceAddress_8[]=POSITION_8;
uint8_t deviceAddress_9[]=POSITION_9;
uint8_t deviceAddress_10[]=POSITION_10;
uint8_t deviceAddress_11[]=POSITION_11;
uint8_t deviceAddress_12[]=POSITION_12;


String temperatureString = (""); 
uint8_t numberOfDevices=0;



void buildTemperatureMessage(uint8_t output) {
  
    Serial.println(F("********buildTemperatureMessage()"));
    numberOfDevices = sensors_m.getDeviceCount();
    Serial.print(F("numberOfDevices = "));
    Serial.println(numberOfDevices);
    sensors_m.requestTemperatures();

    
    
    for(int i=0;i<numberOfDevices; i++)
        {
           if(sensors_m.getAddress(tempDeviceAddress, i))
           {
             Serial.print(F("****device number= "));
             Serial.println(i);
             float tempC = sensors_m.getTempC(tempDeviceAddress);
             String value_18 = String(tempC,1);
             String name_18 = printName(tempDeviceAddress);
             Serial.println(name_18 + ": " + value_18);             

             if (output==0) 
                 {
                      lcd.clear();
                      lcd.setCursor(0, 0); lcd.print(name_18);
                      lcd.setCursor(0, 1);lcd.print(value_18);
                      wifiBasic.enviarPost(name_18, value_18);
                                          
                  }


             if (output==1) 
                 {  
                     lcd.clear();
                     lcd.setCursor(0, 0); lcd.print(name_18);
                     lcd.setCursor(0, 1);lcd.print(value_18);
                     delay(4000);
                  }

             if (output==2) wifiBasic.enviarPost(name_18, value_18);
             

             
           }
        }
}


String printName(DeviceAddress deviceAddress)
{
  
  String temp_sensor_name;

  // Incluye el nombre del sensor
  if     (compareAddress(deviceAddress,deviceAddress_1))  {temp_sensor_name = F((NAME_SENSOR_1));}
  else if(compareAddress(deviceAddress,deviceAddress_2))  {temp_sensor_name = F((NAME_SENSOR_2));} 
  else if(compareAddress(deviceAddress,deviceAddress_3))  {temp_sensor_name = F((NAME_SENSOR_3));} 
  else if(compareAddress(deviceAddress,deviceAddress_4))  {temp_sensor_name = F((NAME_SENSOR_4));} 
  else if(compareAddress(deviceAddress,deviceAddress_5))  {temp_sensor_name = F((NAME_SENSOR_5));}  
  else if(compareAddress(deviceAddress,deviceAddress_6))  {temp_sensor_name = F((NAME_SENSOR_6));} 
  else if(compareAddress(deviceAddress,deviceAddress_7))  {temp_sensor_name = F((NAME_SENSOR_7));}  
  else if(compareAddress(deviceAddress,deviceAddress_8))  {temp_sensor_name = F((NAME_SENSOR_8));}  
  else if(compareAddress(deviceAddress,deviceAddress_9))  {temp_sensor_name = F((NAME_SENSOR_9));} 
  else if(compareAddress(deviceAddress,deviceAddress_10)) {temp_sensor_name = F((NAME_SENSOR_10));} 
  else if(compareAddress(deviceAddress,deviceAddress_11)) {temp_sensor_name = F((NAME_SENSOR_11));} 
  else if(compareAddress(deviceAddress,deviceAddress_12)) {temp_sensor_name = F((NAME_SENSOR_12));}   

  else temp_sensor_name = printAddress(deviceAddress);

 return temp_sensor_name;
 
}

  

bool compareAddress(DeviceAddress deviceAddress_c_1, DeviceAddress deviceAddress_c_2)
  {
    for(int i=0;i<7; i++)
      {
        if (deviceAddress_c_1[i] != deviceAddress_c_2[i]){return false;}
      }
    return true;
  }

void printResoltion(DeviceAddress deviceAddressPr)
{
  temperatureString += (sensors_m.getResolution(deviceAddressPr), DEC); 
}



String printAddress(DeviceAddress deviceAddressPa)
{ 
  String string_temp_r="";
  for (uint8_t i = 0; i < 8; i++)
  {
    if (deviceAddressPa[i] < 16) string_temp_r += ("0");
    uint8_t temp= (deviceAddressPa[i]);
    String stringTemp =  String(temp, HEX);  
    string_temp_r = string_temp_r +stringTemp;
  }
  return string_temp_r;
}

void temperatureSensorsBegin() {sensors_m.begin();}



#endif

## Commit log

2016-10-20 2016-10-19 Acta de reunión del grupo de desarrollo
2016-10-20 borrador de requisitos del demostrador
2016-11-02 [arduino]primera versión sensor temperatura
2016-11-02 cambio de directorio
2016-11-02 nuevo directorio arduino
2016-11-03 [arduino]busqueda sensores de temperatura
2016-11-03 [arduino]autodetecta, comprueba alarmas, lee temperatura
2016-11-04 [arduino]incluse asignacion de nombres a los sensores
2016-11-08 [arduino]mesnajes json, borrar alarma temeperatura
2016-11-08 [arduino]ejemplos json
2016-11-16 [arduino]sensor de presion
2016-11-17 sensor de medida de caudal
2016-11-21 [documentacion] circuito para probar LEN HAS 100S
2016-11-22 [arduino]sensor de intensidad len-has-100s
2016-12-01 [arduino]modulo de prueba de wifi
2016-12-02 [arduino]limpieza codigo wifi
2016-12-06 [arduino]sensor de temperatura por wifi
2016-12-06 [herramientas]cliente para leer de un puerto
2016-12-07 [herramientas] nueva version para leer mensajes
2016-12-08 [herramientas]actualización de herramientas
2016-12-09 [herramientas]cambios en el simulador
2016-12-15 [arduino]cambio de pines asignados
2016-12-21 [arduino]cambios de configuración
2016-12-21 [arduino]borrar libreria keypad
2016-12-28 [arduino] ESP 8266 con comandos basicos
2016-12-29 [arduino]mejoras conexion wifi
2017-01-03 [arduino] wifi operativa contra servidor
2017-01-03 [uwsgi] script de pare recibir post de temperatura
2017-01-11 [arduino]añadidos sensores analógicos + println(F
2017-01-12 [arduino]medidor de caudal por interrupciones
2017-02-01 [arduino]incluidos cambios tipfd_wifi
2017-02-01 [arduino] modificaciones para la pantalla
2017-02-01 [arduino cambio de nombres]
2017-02-08 [hardware]primera version hardware
    [wat.kicad_pcb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]
2017-02-08 [hardware] borro ficheros gerber
    [wat-B.Cu.gbr, wat-B.SilkS.gbr, wat-Edge.Cuts.gbr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]
2017-02-10 [arduino][hardware]midificacion one wire, libreria nuevos componentes
2017-02-18 [arduino]pcb para carril din
    [wat.kicad_pcb, wat.sch]
2017-02-20 Esquema modificado domingo noche
    cambios
    [wat.sch]
2017-02-20 [pcb]mejoras version 3
    [_saved_wat.sch, wat.kicad_pcb]
2017-02-20 [pcb]repongo librerias de huellas
    [_saved_wat.sch, wat.kicad_pcb]
2017-02-21 [pdb] cambio posicion nano
    [_saved_wat.sch, wat.kicad_pcb, wat.sch]
2017-02-24 [pcb]avance version 3
    [_saved_wat.sch, wat.kicad_pcb, wat.sch]
2017-02-25 [pcb]version 3 completa
    [bk_0_wat.sch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]
2017-03-04 [pcb]herramientas actualizar fw del ESP
2017-03-06 [arduino]version para nano
    [wat-B.Cu.gbr, wat-B.SilkS.gbr, wat-Edge.Cuts.gbr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]
2017-03-26 [server]creacion de site()agente por mensaje post
2017-03-28 [arduino]incluyo instalacion endef
2017-04-19 [arduino]actualizar codigo Endef
2017-04-19 [nodemcu]primer codigo de pruebas
2017-04-19 [hardware]borrar informacion obsoleta
    [wat.kicad_pcb, wat.sch]
2017-05-03 [arduino] ultimos cambios para hotel hacienda
2017-05-06 [arduino]codigos 18b20 instalacion hacienda
2017-05-11 [nodemcu]basico para medida de intensidad
2017-05-15 [pcb]version 10
    [bk_0_wat.sch, wat.kicad_pcb, wat.sch]
2017-05-15 [pcb] beta de la pcb
    [wat.kicad_pcb, wat.sch]
2017-05-15 [pcb] mejoras menores
    [wat.kicad_pcb]
2017-05-31 [hardware]v10 y pinza
    [pinza.kicad_pcb, pinza.sch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]
2017-05-31 [nodemcu medida de intensidad]
2017-06-03 [nodemcu]irms y wifi
    [pinza.kicad_pcb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]
2017-06-17 [pcb]version_11 pinzas de consumo
    [bk_0_wat.sch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]
2017-07-16 [nodemcu]pruebas bajar a cerpo la Irms
2017-07-16 [hardware]pinza nodemcu
    [pinza.kicad_pcb, pinza.sch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]
2017-07-16 [nodemcu]fichero de wifi
2018-04-06 primera correccion de oscar
